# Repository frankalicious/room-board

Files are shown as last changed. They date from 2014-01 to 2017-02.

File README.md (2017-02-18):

room-board-schematic
====================
# hardware
- MSP430G2553IN20
- pir module
- brightness measuring with led (kicad version uses phototransistor)
- nrf24l01 radio module

# gateway
https://github.com/frankalicious/nrf24l01-serial-gateway

# old schematic
gschem was used for first schematic version

# current schematic and board
designed in kicad

# git submodule
msp430-gcc firmware uses msprf24
```bash
$ git submodule init
$ git submodule update
```
For more information about git submodules see here: http://git-scm.com/book/en/v2/Git-Tools-Submodules

Use firmware/msp430-gcc/.
firmware/Enrf24_TXdemo_with_PIR/ does not seem to work

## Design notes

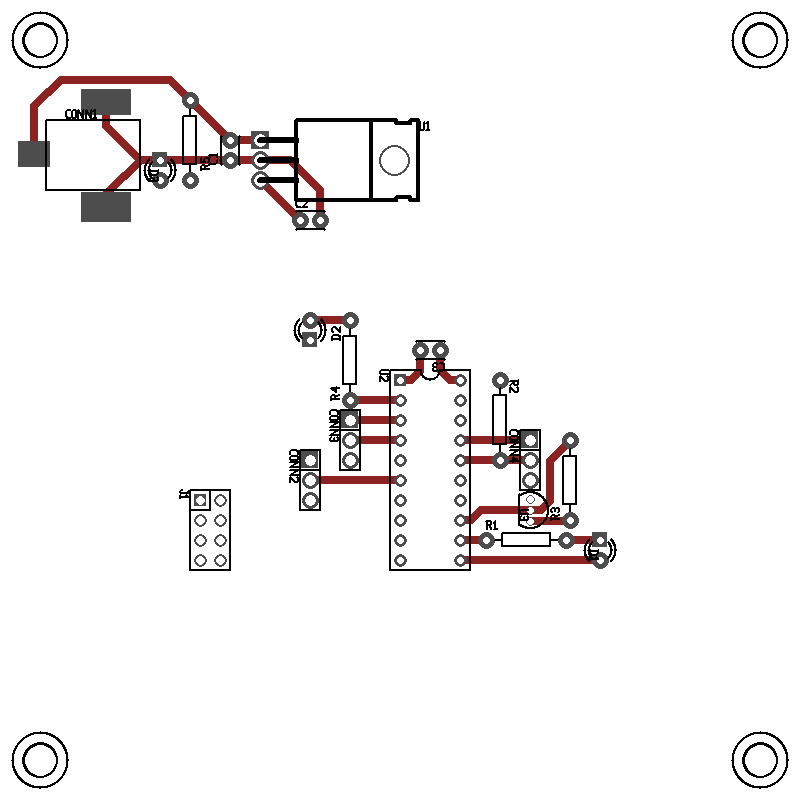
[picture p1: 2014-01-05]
schematic/board.png

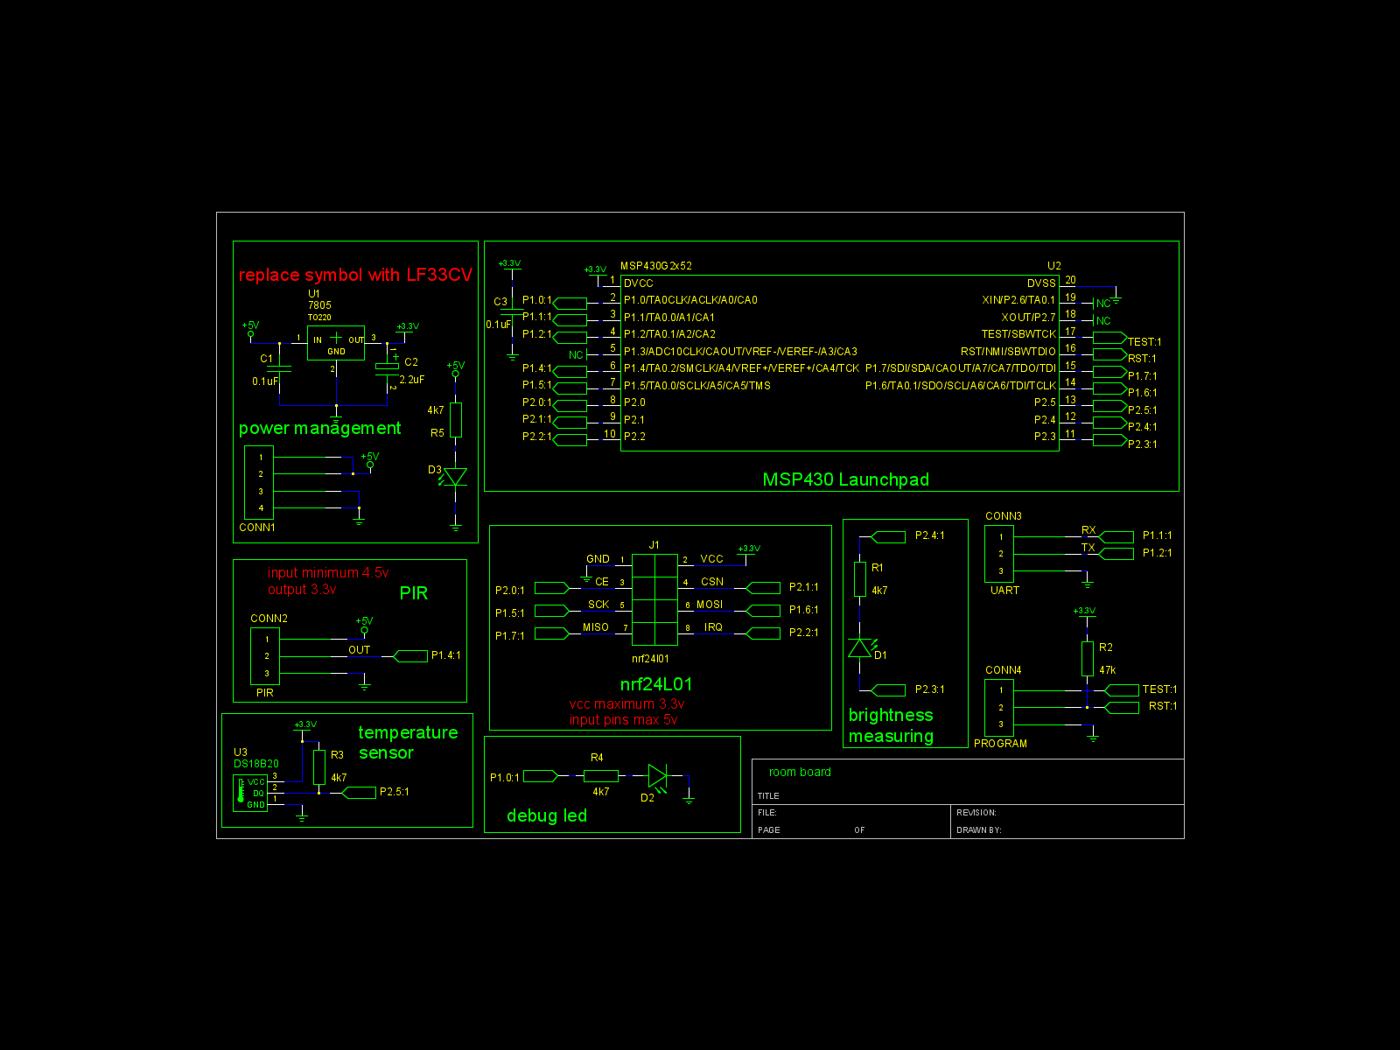
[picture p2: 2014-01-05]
schematic/room-board.png

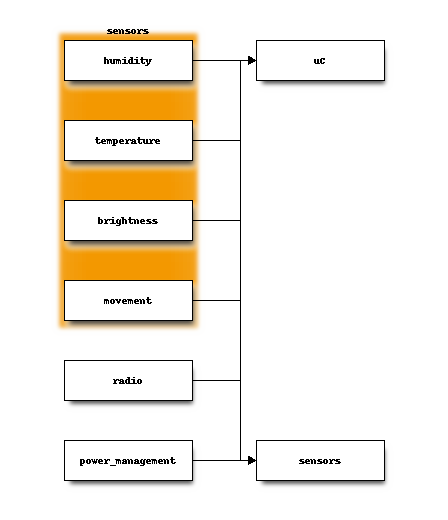
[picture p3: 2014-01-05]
diagram/room-board.png

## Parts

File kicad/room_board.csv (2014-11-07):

Id | Designator | Package | Quantity | Designation | Supplier and ref
1 | U1 | Sockets_DIP:DIP-20__300 | 1 | MSP430G2452IN20
2 | C1,C2,C4 | Discret:C1 | 3 | 100nF
3 | C3 | Discret:C1 | 1 | 2u2F
4 | D1,D3 | LEDs:LED-5MM | 2 | LED
5 | R1,R4 | Discret:R3 | 2 | 4k7
6 | U2 | Discret:LM78XXV | 1 | 7805
7 | R2,R3 | Discret:R3 | 2 | 10k
8 | U3 | Pin_Headers:Pin_Header_Straight_1x04 | 1 | DHT
9 | HDR1,HDR4 | ab2_header:AB2_HDR_M03-1V | 2 | AB2_HDR03-1
10 | D2 | LEDs:LED-5MM | 1 | SFH 300
11 | HDR2 | ab2_header:AB2_HDR_M04-2V | 1 | AB2_HDR04-2
12 | HDR3 | ab2_header:AB2_HDR_M03-1V | 1 | UART
13 | R5 | Discret:R3 | 1 | 47k
14 | K1 | ab2_power:AB2_PB_2MM_JACK_PTH | 1 | CONN_3
15 | SYM | Symbols:Symbol_OSHW-Logo_SilkScreen | 1 | Symbol_OSHW-Logo_SilkScreen_07Jul2012
16 | HDR5 | ab2_header:AB2_HDR_M02-1V | 1 | AB2_HDR02-1

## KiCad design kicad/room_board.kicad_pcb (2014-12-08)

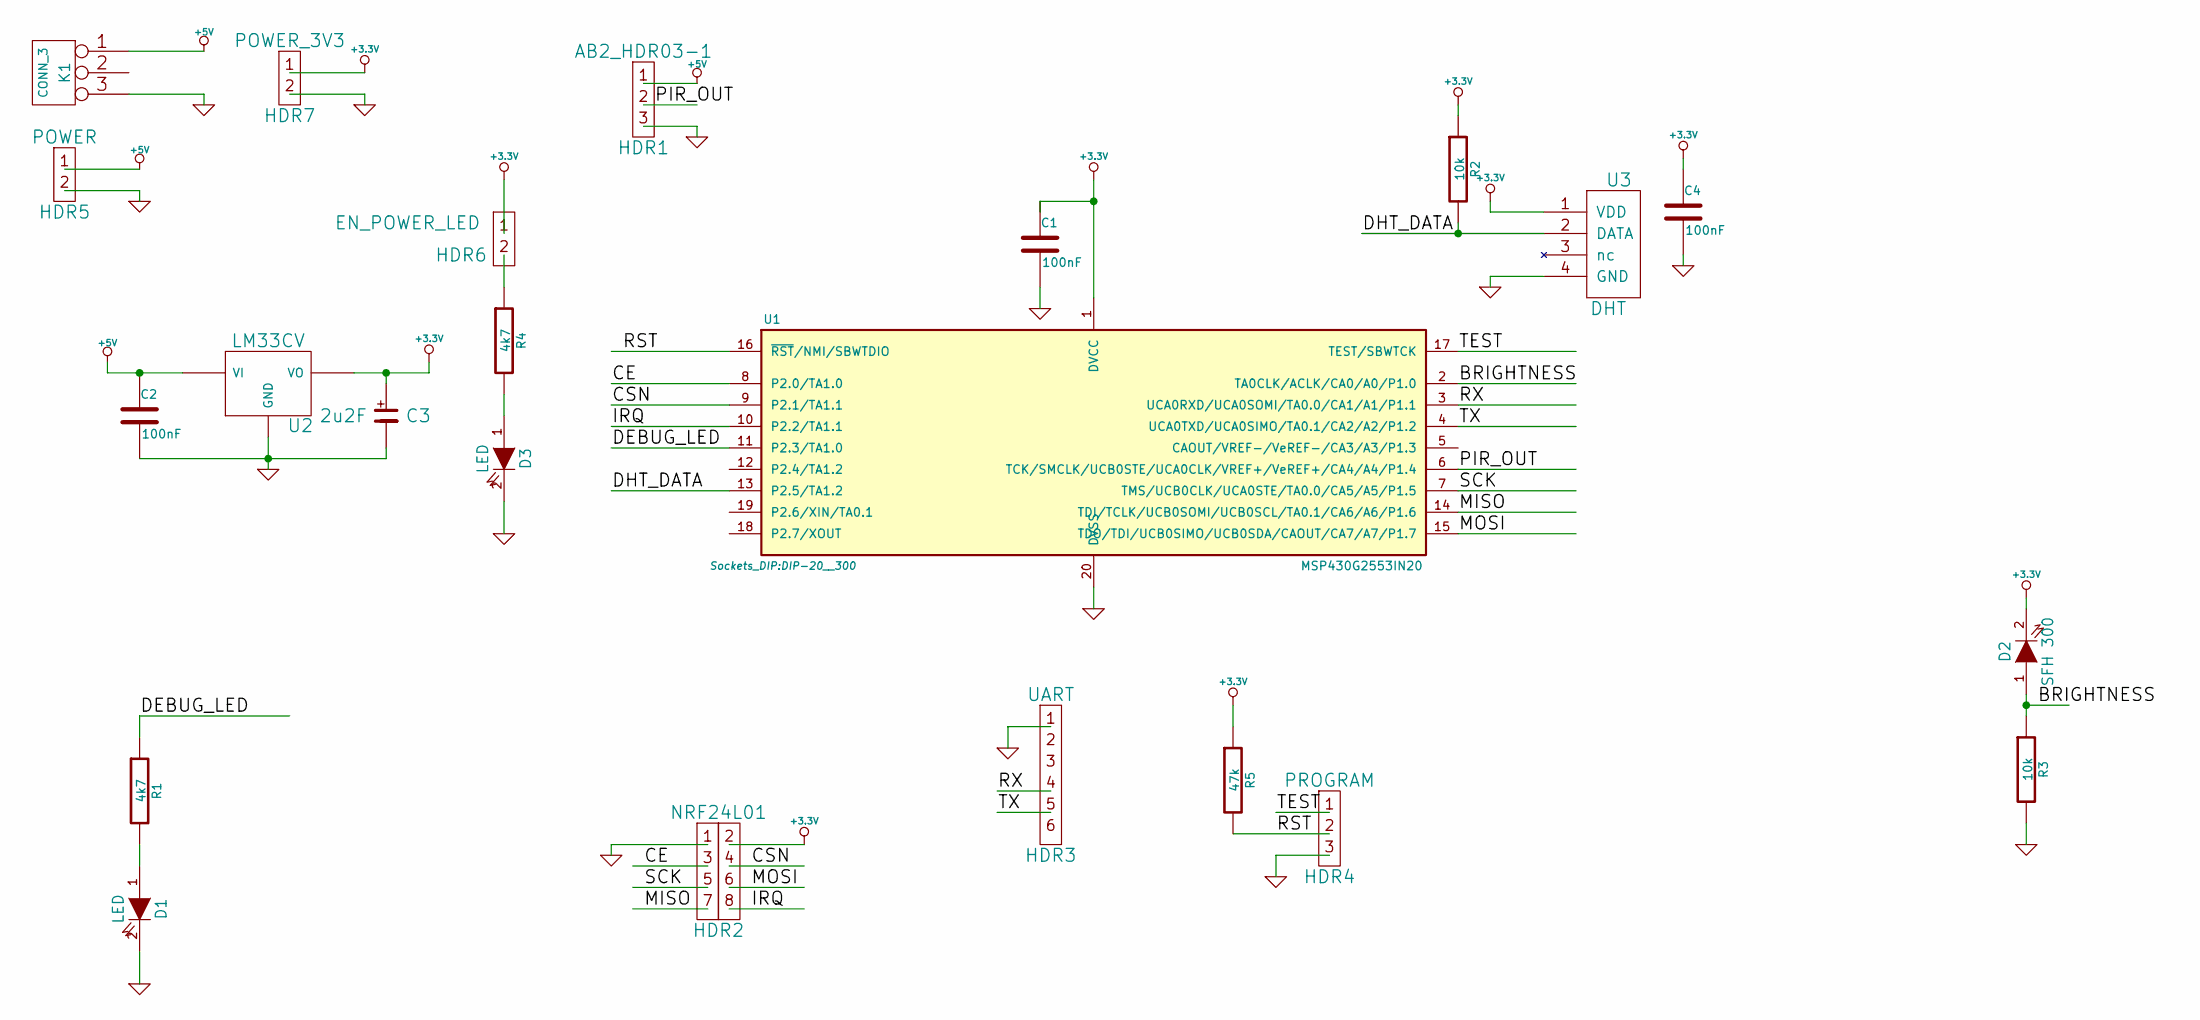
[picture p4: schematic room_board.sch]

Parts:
C1, C2, C4: 100nF; C1
C3: 2u2F; Elko_vert_11x5mm_RM2.5
D1, D3: LED; LED-5MM
D2: SFH 300; LED-5MM
HDR1: AB2_HDR03-1; AB2_HDR_M03-1V
HDR2: NRF24L01; AB2_HDR_M04-2V
HDR3: UART; AB2_HDR_M06-1V
HDR4: PROGRAM; AB2_HDR_M03-1V
HDR5: POWER; AB2_HDR_M02-1V
HDR6: EN_POWER_LED; AB2_HDR_M02-1V
HDR7: POWER_3V3; AB2_HDR_M02-1V
K1: CONN_3; AB2_PB_2MM_JACK_PTH
R1, R4: 4k7; R3
R2, R3: 10k; R3
R5: 47k; R3
U1: MSP430G2553IN20; DIP-20__300
U2: LM33CV; LM78XXV
U3: DHT; Pin_Header_Straight_1x04

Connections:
+3.3V: C1.1, C3.1 (A), C4.1, D2.2 (K), HDR2.2, HDR6.1, HDR7.1, R2.1, R5.1, U1.1 (DVCC), U2.VO, U3.1 (VDD)
+5V: C2.1, HDR1.1, HDR5.1, K1.1, U2.VI
/BRIGHTNESS: D2.1 (A), R3.1, U1.2 (TA0CLK/ACLK/CA0/A0/P1.0)
/CE: HDR2.3, U1.8 (P2.0/TA1.0)
/CSN: HDR2.4, U1.9 (P2.1/TA1.1)
/DEBUG_LED: R1.1, U1.11 (P2.3/TA1.0)
/DHT_DATA: R2.2, U1.13 (P2.5/TA1.2), U3.2 (DATA)
/IRQ: HDR2.8, U1.10 (P2.2/TA1.1)
/MISO: HDR2.7, U1.14 (TDI/TCLK/UCB0SOMI/UCB0SCL/TA0.1/CA6/A6/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)
/MOSI: HDR2.6, U1.15 (TDO/TDI/UCB0SIMO/UCB0SDA/CAOUT/CA7/A7/P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)
/PIR_OUT: HDR1.2, U1.6 (TCK/SMCLK/UCB0STE/UCA0CLK/VREF+/VeREF+/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)
/RST: HDR4.2, R5.2, U1.16 (~RST~/NMI/SBWTDIO)
/RX: HDR3.4, U1.3 (UCA0RXD/UCA0SOMI/TA0.0/CA1/A1/P1.1)
/SCK: HDR2.5, U1.7 (TMS/UCB0CLK/UCA0STE/TA0.0/CA5/A5/P1.5)
/TEST: HDR4.1, U1.17 (TEST/SBWTCK)
/TX: HDR3.5, U1.4 (UCA0TXD/UCA0SIMO/TA0.1/CA2/A2/P1.2)
GND: C1.2, C2.2, C3.2 (K), C4.2, D1.2 (K), D3.2 (K), HDR1.3, HDR2.1, HDR3.1, HDR4.3, HDR5.2, HDR7.2, K1.3, R3.2, U1.20 (DVSS), U2.GND, U3.4 (GND)
unnamed: D1.1 (A), R1.2
unnamed: D3.1 (A), R4.2
unnamed: HDR6.2, R4.1

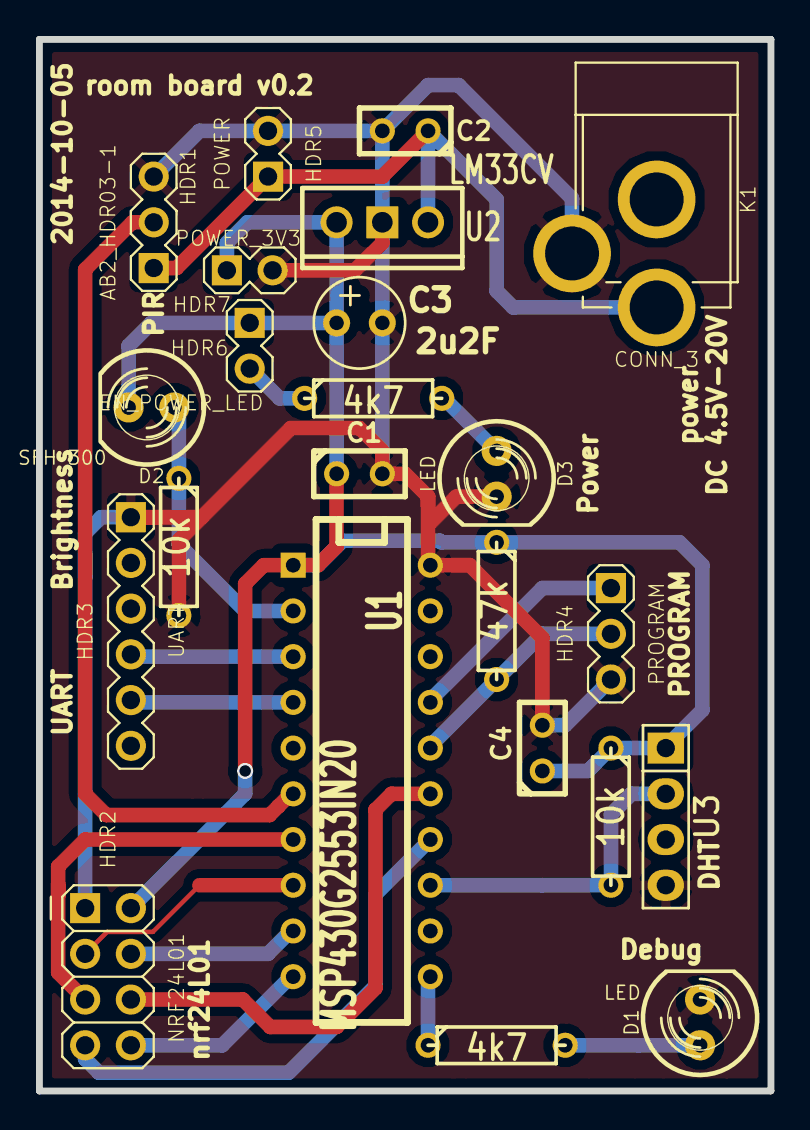
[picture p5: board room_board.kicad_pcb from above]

Board: 2 copper layers, 40.6 x 58.4 mm, 23 parts (0 on the bottom side), 20 nets.

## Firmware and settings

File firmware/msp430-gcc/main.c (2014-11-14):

#include <msp430.h>
#include <stdlib.h>
#include <string.h>
#include "uart/uart.h"
#include "adc/adc.h"
#include "stdbool.h"
#include "DHT11_LIB/DHT11_LIB.h"
#include "msprf24/msprf24.h"
#include "msprf24/nrf_userconfig.h"

#define     LED BIT3
#define     LED_DIR P2DIR
#define     LED_OUT P2OUT
#define     LED_OFF (LED_OUT &= ~LED)
#define     LED_ON (LED_OUT |= LED)
#define     LED_TOGGLE (LED_OUT ^= LED)

/* #define NODE "010" /\* perf board version *\/ */
/* #define NODE "011" /\* launchpad version *\/ */
#define NODE "012" /* osh park version */

#define SEPARATOR ";"

unsigned char volatile TOUT;			/* REQUIRED for library */
unsigned char volatile SECOND_TIMER=0;

unsigned char RH_byte1;
unsigned char RH_byte2;
unsigned char T_byte1;
unsigned char T_byte2;
unsigned char checksum;

unsigned char Packet[5];

volatile unsigned int user;

void init_led(void);
void uart_rx_isr(unsigned char c);
void delay_ms(unsigned int ms);
void get_dht(void);
void init_dht (void);
void print_dht (void);
void init_nrf24 (void);
void check_nrf24 (void);
void send_nrf24 (void);
void create_string(char* payload, int brightness, int sensorValue, uint8_t temperature, uint8_t humidity);
void print_string(char* payload, int brightness, int sensorValue, uint8_t temperature, uint8_t humidity);

__interrupt void CCR0_ISR(void);

#pragma vector = TIMER0_A0_VECTOR
__interrupt void CCR0_ISR(void){
  SECOND_TIMER++;
  TOUT=1;
  /* TOG (P1OUT,0x01); */
  CLR (TACCTL0, CCIFG);
}
void create_string(char* payload, int brightness, int sensorValue, uint8_t temperature, uint8_t humidity)
{
  char buffer[4];
  int index;
  /* todo: zeroize not needed if strcpy is used for first char? */
  /* strcpy(payload,"N"); */
  for ( index= 0; index < 21; index++)
    payload[index] = 0;
  payload[0] = 'N';
  strcat(payload,NODE);
  strcat(payload,SEPARATOR);
  strcat(payload,"B");
  if (brightness <10)
    strcat(payload, "00");
  else if (brightness <100)
    strcat(payload, "0");
  itoa(brightness,buffer,10);
  strcat(payload, buffer);
  strcat(payload,SEPARATOR);
  strcat(payload,"M");
  strcat(payload,"00");
  itoa(sensorValue,buffer,10);
  strcat(payload, buffer);
  strcat(payload,SEPARATOR);
  strcat(payload,"T");
  if (temperature <10)
    strcat(payload, "00");
  else if (temperature <100)
    strcat(payload, "0");
  itoa(temperature,buffer,10);
  strcat(payload, buffer);
  strcat(payload,SEPARATOR);
  strcat(payload,"H");
  if (humidity <10)
    strcat(payload, "00");
  else if (humidity <100)
    strcat(payload, "0");
  itoa(humidity,buffer,10);
  strcat(payload, buffer);
}

void print_string(char* payload, int brightness, int sensorValue, uint8_t temperature, uint8_t humidity)
{
  char buffer[10];
  uart_puts("Sending packet: ");
#if 0
  char* act_char = &payload[0];
  uart_puts("Sending packet: ");
  while (*act_char)
  {
    itoa(*act_char,buffer,10);
    uart_puts(buffer);
    uart_puts(" ");
    act_char++;
  }
#endif
  uart_puts(&payload[0]);
  uart_puts("\r\n");
  uart_puts("sensor value: ");
  itoa(sensorValue,buffer,10);
  uart_puts(buffer);
  uart_puts("\r\n");
  uart_puts("brightness: ");
  itoa(brightness,buffer,10);
  uart_puts(buffer);
  uart_puts("\r\n");
  uart_puts("temperature: ");
  itoa(temperature,buffer,10);
  uart_puts(buffer);
  uart_puts("\r\n");
  uart_puts("humidity: ");
  itoa(humidity,buffer,10);
  uart_puts(buffer);
  uart_puts("\r\n");
}

void init_nrf24(void)
{
  uint8_t addr[5];

  /* Initial values for nRF24L01+ library config variables */
  rf_crc = RF24_EN_CRC; /* CRC enabled, 8-bit */
  rf_addr_width      = 5;
  rf_speed_power     = RF24_SPEED_1MBPS | RF24_POWER_MAX;
  rf_channel         = 0;
  msprf24_init();
  msprf24_set_pipe_packetsize(0, 0); /* dynamic */
  msprf24_open_pipe(0, 1);  /* Open pipe#0 with Enhanced ShockBurst */

  /* Set our RX address */
  addr[0] = 0xDE;
  addr[1] = 0xAD;
  addr[2] = 0xBE;
  addr[3] = 0xEF;
  addr[4] = 0x01;

  w_tx_addr(addr);
  w_rx_addr(0, addr);  /* Pipe 0 receives auto-ack's, autoacks are sent back to the TX addr so the PTX node */
  /* needs to listen to the TX addr on pipe#0 to receive them. */
  msprf24_standby();
  user = msprf24_current_state();
#if 0
  /* Receive mode */
  if (!(RF24_QUEUE_RXEMPTY & msprf24_queue_state())) {
    flush_rx();
  }
  msprf24_activate_rx();
#endif
}

void check_nrf24(void)
{
  uint8_t buf[32];

  if (rf_irq & RF24_IRQ_FLAGGED) {
    msprf24_get_irq_reason();
  }
  if (rf_irq & RF24_IRQ_RX || msprf24_rx_pending()) {
    r_rx_payload(32, buf);
    msprf24_irq_clear(RF24_IRQ_RX);
    user = buf[0];
    uart_puts("nrf24 received!\r\n");
  } else {
    user = 0xFF;
  }
}

void send_nrf24 (void)
{
  char buf[32];
  char buffer[10];
  uint8_t sensor = 1;
  user = msprf24_current_state();
  itoa(user,buffer,10);
  uart_puts("current state: ");
  uart_puts(buffer);
  uart_puts("\r\n");

  create_string(&buf[0], ADCValue, sensor, T_byte1, RH_byte1);
  print_string(&buf[0], ADCValue, sensor, T_byte1, RH_byte1);
  w_tx_payload(32, (uint8_t*)buf);
  msprf24_activate_tx();
  user = msprf24_get_last_retransmits();
  itoa(user,buffer,10);
  uart_puts("last retransmit: ");
  uart_puts(buffer);
  uart_puts("\r\n");
}

void get_dht(void)
{
  /* Must wait 1 second initially and between all reads */
  if(SECOND_TIMER >= 5){		/* 5 @ CCR0 = 50000 & div 4 */
    /* Manual way to gather all data without array */
    /*
      start_Signal();
      if(check_Response()){
      RH_byte1 = read_Byte();
      RH_byte2 = read_Byte();
      T_byte1 = read_Byte();
      T_byte2 = read_Byte();
      checksum = read_Byte();
      }
    */

    /* Simple way to gather all data with one instruction */
    read_Packet(Packet);
    RH_byte1 =	Packet[0];
    RH_byte2 =	Packet[1];
    T_byte1 =	Packet[2];
    T_byte2 =	Packet[3];
    checksum =	Packet[4];

    /* if (check_Checksum(Packet)) */
    /* SET (P1OUT, 0x40); */

    SET (TACTL, TACLR);
    SET (TA0CTL, 0x10);
    TACCR0 = 50000;		/* Initialize the timer to count at 5Hz */
    SECOND_TIMER = 0;	/* Clear counter */
  }
}

void init_dht (void)
{
  TACCR0 = 50000;				/* Initialize the timer to count at 5Hz */
  TACCTL0 = CCIE;				/* Enable interrupt */
  TA0CTL = TASSEL_2 + ID_2 + MC_1 + TACLR;	/* SMCLK, div 4, up mode, */
}

void print_dht (void)
{
  char buffer[10];
/*
  itoa(RH_byte1,buffer,10);
  uart_puts(buffer);
  uart_puts(" ");
  itoa(RH_byte2,buffer,10);
  uart_puts(buffer);
  uart_puts(" ");
  itoa(T_byte1,buffer,10);
  uart_puts(buffer);
  uart_puts(" ");
  itoa(T_byte2,buffer,10);
  uart_puts(buffer);
  uart_puts(" ");
  itoa(checksum,buffer,10);
  uart_puts(buffer);
  uart_puts(" ");
  uart_puts("\r\n");
*/
  uart_puts("Humidity: ");
  itoa(RH_byte1,buffer,10);
  uart_puts(buffer);
  uart_puts("\tTemperature: ");
  itoa(T_byte1,buffer,10);
  uart_puts(buffer);
  uart_puts("\tChecksum: ");
  itoa(checksum,buffer,10);
  uart_puts(buffer);
  uart_puts("\r\n");
}

void delay_ms(unsigned int ms){
  while(ms--){
    __delay_cycles(1000);
  }
}

void init_led(void)
{
  LED_DIR |= LED;
  LED_OFF;
}

void uart_rx_isr(unsigned char c) {
  uart_putc(c);
  /* P1OUT ^= BIT0;		// toggle P1.0 (red led) */
}

int main(void)
{
  WDTCTL = WDTPW + WDTHOLD;                  /* Stop WDT */
  BCSCTL1 = CALBC1_1MHZ; /* Set range */
  DCOCTL = CALDCO_1MHZ; /* SMCLK = DCO = 1MHz */
  uart_init();

  /* register ISR called when data was received */
  uart_set_rx_isr_ptr(uart_rx_isr);

  /* init_spi(); */
  /* init_nrf24l01 */
  /* init_adc();                   /\* not needed? *\/ */
  init_led();
  init_dht();
  init_nrf24();
  __bis_SR_register(GIE);

  uart_puts((char *)"\n\r***************\n\r");
  uart_puts((char *)"room board\n\r");
  uart_puts((char *)"***************\n\r\n\r");

  ADCDone = false;
  Single_Measure(INCH_0);
#if 0
  Single_Measure_REF(INCH_10, 0);	/* Reads the temperature sensor once */
  Single_Measure_REF(INCH_11, REF2_5V);	/* Reads VCC once (VCC/2 internally) */
#endif
  while(1)
  {
    char buffer[10];
    /* unsigned volt; */
    get_dht();
    print_dht();

    delay_ms(1000);
    /* volt = read_voltage(); */
    /* itoa(volt,buffer,10); */
    /* uart_puts("Brightness: "); */
    /* uart_puts(buffer); */
    /* uart_puts("\r\n"); */
    if (ADCDone)
    {
      LED_TOGGLE;
      itoa(ADCValue,buffer,10);
      uart_puts("Brightness: ");
      uart_puts(buffer);
      uart_puts("\r\n");
      ADCDone = false;
      Single_Measure(INCH_0);
#if 0
      __bis_SR_register(GIE);   /* check if working */
      LPM0;   /* check if working */
#endif
    }
    check_nrf24();
    send_nrf24();
  }
}

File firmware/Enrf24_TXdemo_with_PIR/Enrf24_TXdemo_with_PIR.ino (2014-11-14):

#include <Enrf24.h>
#include <nRF24L01.h>
#include <string.h>
#include <SPI.h>

// node 10, brightness 100, movement detected
// N010;B100;M001

// node 10, brightness 5, no movement detected
// N010;B005;M000

#define NODE "010" /* perf board version */
// #define NODE "011" /* launchpad version */
#define SEPARATOR ";"

#define DEBUG_LED
#define MEASURE_BRIGHTNESS
#define MEASURE_TEMPERATURE

// msp430g2452, pir sensor, nrf24l01
Enrf24 radio(P2_0, P2_1, P2_2);  // P2.0=CE, P2.1=CSN, P2.2=IRQ
const uint8_t txaddr[] = { 
  0xDE, 0xAD, 0xBE, 0xEF, 0x01 };

#define PIRPIN P1_4

#define ANODE P2_3
#define CATHODE P2_4
//usage led
//led on: ANODE +, CATHODE -
//led off: ANODE -, CATHODE don't care

//usage brightness:
//load led: ANODE -, CATHODE +

#define LIGHT_DARK_BOUNDARY 100

//http://arduino.cc/en/Tutorial/Smoothing
const int numReadings = 10;

int readings[numReadings];      // the readings from the analog input
int index = 0;                  // the index of the current reading
int total = 0;                  // the running total
int average = 0;                // the average


void dump_radio_status_to_serialport(uint8_t);

void setup() {
  Serial.begin(9600);

  SPI.begin();
  SPI.setDataMode(SPI_MODE0);
  SPI.setBitOrder(1); // MSB-first

  radio.begin();  // Defaults 1Mbps, channel 0, max TX power
  dump_radio_status_to_serialport(radio.radioState());

  radio.setTXaddress((void*)txaddr);

  pinMode(PIRPIN, INPUT_PULLUP);
#ifdef MEASURE_BRIGHTNESS
  pinMode(ANODE, OUTPUT);
  pinMode(CATHODE, OUTPUT);
#endif
#ifdef DEBUG_LED
  pinMode(RED_LED, OUTPUT);
#endif

  // initialize all the readings to 0:
  for (int thisReading = 0; thisReading < numReadings; thisReading++)
    readings[thisReading] = 0;
#ifdef MEASURE_TEMPERATURE
  setup_temp();
#endif
}

void loop() {
  static int lastValue=0;
  static int lastBrightness=0;
  static int brightness=0;
  unsigned int brightnessChanged=0;
#ifdef MEASURE_TEMPERATURE
  byte temperature = loadTemperature(1);
#else
  byte temperature = 0;
#endif
  //Serial.print("brightness = ");  
  //Serial.println(measure_brightness());  
  //brightness = measure_brightness();

#ifdef MEASURE_BRIGHTNESS
/*
  if (lastValue == 0)//only measure brightness if light turned off
  {
    brightness = smooth_brightness();
  }
*/
  //try if it works if brightness is always measured
  brightness = smooth_brightness();
    
  if (brightness < (lastBrightness - 10) || 
      brightness > (lastBrightness+10))
  {
    brightnessChanged = 1;
  }
#else
  brightness = 255;//for testing without brightness sensor
#endif
  int sensorValue = digitalRead(PIRPIN);

  if (sensorValue != lastValue || brightnessChanged)
  {
#ifdef DEBUG_LED
    if (sensorValue)
      digitalWrite(RED_LED, HIGH);
    else
      digitalWrite(RED_LED, LOW);
#endif

    char payload[21];
    create_string(&payload[0], brightness, sensorValue, temperature);
    print_string(&payload[0], brightness, sensorValue, temperature);
    send_string(&payload[0]);
    delay(1000); //TODO: do we need this delay?
  }
  lastValue = sensorValue;
  lastBrightness = brightness;
#ifdef MEASURE_TEMPERATURE
  loop_temp();
#endif
}

void dump_radio_status_to_serialport(uint8_t status)
{
  Serial.print("Enrf24 radio transceiver status: ");
  switch (status) {
  case ENRF24_STATE_NOTPRESENT:
    Serial.println("NO TRANSCEIVER PRESENT");
    break;

  case ENRF24_STATE_DEEPSLEEP:
    Serial.println("DEEP SLEEP <1uA power consumption");
    break;

  case ENRF24_STATE_IDLE:
    Serial.println("IDLE module powered up w/ oscillators running");
    break;

  case ENRF24_STATE_PTX:
    Serial.println("Actively Transmitting");
    break;

  case ENRF24_STATE_PRX:
    Serial.println("Receive Mode");
    break;

  default:
    Serial.println("UNKNOWN STATUS CODE");
  }
}

uint8_t measure_brightness()
{
  uint8_t brightness = 0;
  //load led
  pinMode(CATHODE, OUTPUT);
  digitalWrite(CATHODE, HIGH);
  pinMode(ANODE, OUTPUT);
  digitalWrite(ANODE, LOW);
  delayMicroseconds(10);

  //measure time till cathode low
  pinMode(CATHODE, INPUT);
  while ( digitalRead(CATHODE) && brightness != 0xff)
  {
    brightness++;
    //delayMicroseconds(100);
    delay(1);
  }
  return brightness;  
}

uint8_t smooth_brightness()
{
  // subtract the last reading:
  total= total - readings[index];        
  // read from the sensor:  
  readings[index] = measure_brightness();
  // add the reading to the total:
  total= total + readings[index];      
  // advance to the next position in the array:  
  index = index + 1;                    

  // if we're at the end of the array...
  if (index >= numReadings)              
    // ...wrap around to the beginning:
    index = 0;                          

  // calculate the average:
  average = total / numReadings;        
  // send it to the computer as ASCII digits
  return (uint8_t) average;
}

void create_string(char* payload, int brightness, int sensorValue, byte temperature)
{
  char buffer[4];
  // todo: zeroize not needed if strcpy is used for first char?
  // strcpy(payload,"N");
  for (int index = 0; index < 21; index++)
    payload[index] = 0;
  payload[0] = 'N';
  strcat(payload,NODE);
  strcat(payload,SEPARATOR);
  strcat(payload,"B");
  if (brightness <10)
    strcat(payload, "00");
  else if (brightness <100)
    strcat(payload, "0");
  itoa(brightness,buffer,10);
  strcat(payload, buffer);
  strcat(payload,SEPARATOR);
  strcat(payload,"M");
  strcat(payload,"00");
  itoa(sensorValue,buffer,10);
  strcat(payload, buffer);
  strcat(payload,SEPARATOR);
  strcat(payload,"T");
  if (temperature <10)
    strcat(payload, "00");
  else if (temperature <100)
    strcat(payload, "0");
  itoa(temperature,buffer,10);
  strcat(payload, buffer);
  payload[20] = 0;
}

void print_string(char* payload, int brightness, int sensorValue, byte temperature)
{
  Serial.print("Sending packet: ");
  Serial.println(payload);
  Serial.print("sensor value: ");
  Serial.println(sensorValue);
  Serial.print("brightness: ");
  Serial.println(brightness);
  Serial.print("temperature: ");
  Serial.println(temperature);

}

void send_string(char* payload)
{
  radio.print(payload);
  radio.flush();  // Force transmit (don't wait for any more data)
  //dump_radio_status_to_serialport(radio.radioState());  // Should report IDLE
}

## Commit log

2013-12-17 add preliminary schematic
    [room-board.sch]
2013-12-17 move schematic to subdirectory
    [room-board.sch]
2014-01-05 update schematic
    - add most of the components
    [room-board.sch]
2014-01-05 update firmware
    - add temperaturemeassurement
2014-01-05 add preliminary pcb
2014-01-05 add picture of schematic
2014-02-23 split functions in endless loop
    seperate in create_string, print_string ans send string
2014-02-23 exchange MOSI and MISO on nrf24L01+
    They have been swapped.
    [room-board.sch]
2014-02-23 fix parenthesis from commit 6f576f7
    Silly me set the parenthesis wrong which lends to wrong temperature values.
2014-10-04 add kicad files
    2 layer board
    [room_board.csv, room_board.kicad_pcb, room_board.sch]
2014-10-04 Update README.md
    update readme for kicad changes
2014-10-05 update files sent to osh park for board creation
    [room_board-B_Cu.gbl, room_board-B_Mask.gbs, room_board-B_Paste.gbp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]
2014-11-07 update kicad schematic
    [room_board.csv, room_board.kicad_pcb, room_board.sch]
2014-11-07 add check if temperature should be measured in ernergia sketch
2014-11-07 schematic: add todo to change c3
    According to the datasheet of the lm33cv c3 has to be an electrolyt capacitor and not a default capacitor.
    [room_board.sch]
2014-11-09 move submodules to subfolders (adc/uart/etc) and adjust makefile
2014-11-09 fix include of header files
    The modules were moved to subdirectories.
    Therefore the including in the main file have to be fixed.
    [main.c]
2014-11-09 remove unused line in uart module
    Because of the comment style there was a warning.
2014-11-09 init msp430 clock
    To get a stable msp430 clock for uart initialize the clock.
2014-11-09 add helper macro to toggle debug led
2014-11-09 measure adc value
    For now without interrupt because the interrupt did not work.
    [main.c]
2014-11-09 add code for dht11 temperature and humidity measuring
    Add dht11 code from https://github.com/bafeigum/DHT11-Library-for-MSP430.
    Changed the comments from // to /*. Otherwise there are a a lot of gcc warnings with the settings in the makefile.
2014-11-09 move adc non intterupt version to adc module
2014-11-09 fix adc interrupt service routine
    The pragma for the irq was missing.
    [adc.c]
2014-11-09 use interrupt version of adc
2014-11-09 fix comment style in energia sketch
    [Enrf24_TXdemo_with_PIR.ino]
2014-11-14 wip msp430 nrf24l01
    does not work
    [main.c]
2014-11-14 fix setting of nrf24l01 baudrate and power
    Set the nrf24l01 baudrate to the same as the receiver.
    Also set the power to max.
    [main.c]
2014-12-01 add used symbols in schematic
    The symbols are in the cache library in the project path.
2014-12-06 add jumper for power led
    Enable possibility to turn off power led to reduce power consumption when using a battery.
    [room_board.sch]
2014-12-06 move dht to border
    The former position of the DHT was under the nrf24l01.
    Fixes #4.
    [room_board.kicad_pcb]
2014-12-06 replace capacitory with electrolytic version
    The LCV33CV needs an electrolytic capacitor on it's output.
    Fix in schematic and pcb.
    [room_board.kicad_pcb, room_board.sch]
2014-12-08 update schematic/layout
    - replace LM7805 symbol with LM33CV in schematic and layout
    - add 3.3V power connector in schematic and layout
    - replace 3pin uart with 6pin. only in schematic not done yet in layout
    [room_board.kicad_pcb, room_board.sch]
2014-12-08 fix layout of uart connector
    [room_board.kicad_pcb, room_board.sch]
